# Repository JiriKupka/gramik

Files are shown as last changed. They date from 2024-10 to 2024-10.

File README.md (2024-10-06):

# Gramik

[🇬🇧 EN](README.md) | [🇨🇿 CZ](README.cs.md)

## Intro
Our little daughter enjoys music. When she was just a few months old, she received the book "[My First Mozart](https://www.axioma.cz/obchod/muj-prvni-mozart/)," which kept her entertained for countless hours. This was followed by books like "[My Little Beethoven](https://www.svojtka.cz/muj-maly-beethoven/)" or "[Rock and Roll, Baby!](https://www.axioma.cz/obchod/rokenrol-bejby-2/)." Once, we had a Chuck Berry record playing on our turntable at home. It was right around the time our daughter had just learned to walk. She stood up, leaned on the record table, and happily started shaking her hips. Around that time, the idea for the "Gramík Project" began to form in my head. The project went through several iterations—from a prototype made of ready-made modules on a breadboard, to the first PCB design with the thought of giving it some form, and finally to the current version, which I felt I could release and make available to everyone.

My main idea was to create a simple music box with a few buttons that would recognize what playlist or folder to play when a certain medium is placed on it and a button is pressed. The choice of identification medium fell on RFID chips, with an easily available and inexpensive RFID reader on the Gramík side. The first prototype was built using an ESP8266 and an MP3 module, which worked nicely, but I wanted the whole solution to be more compact, so I iterated to the version with a Raspberry Pi on a PCB.

| | | |
| --- | --- | --- |
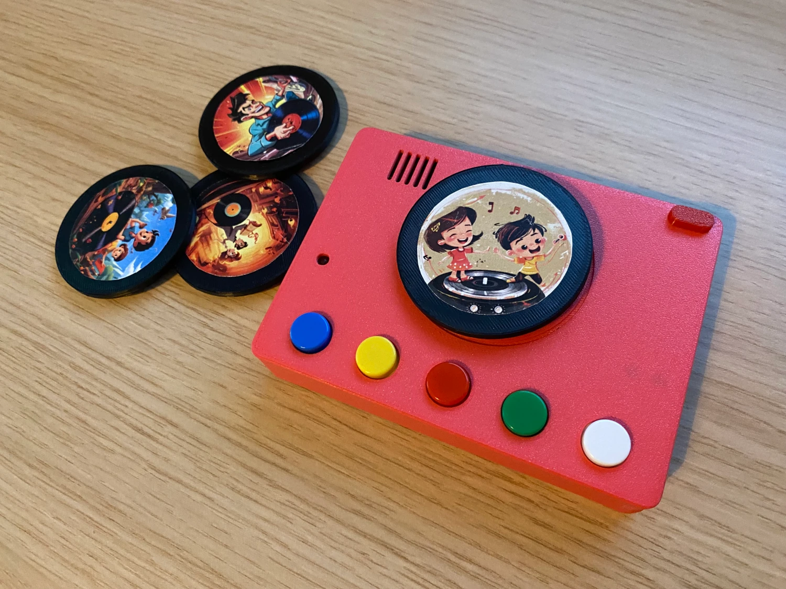
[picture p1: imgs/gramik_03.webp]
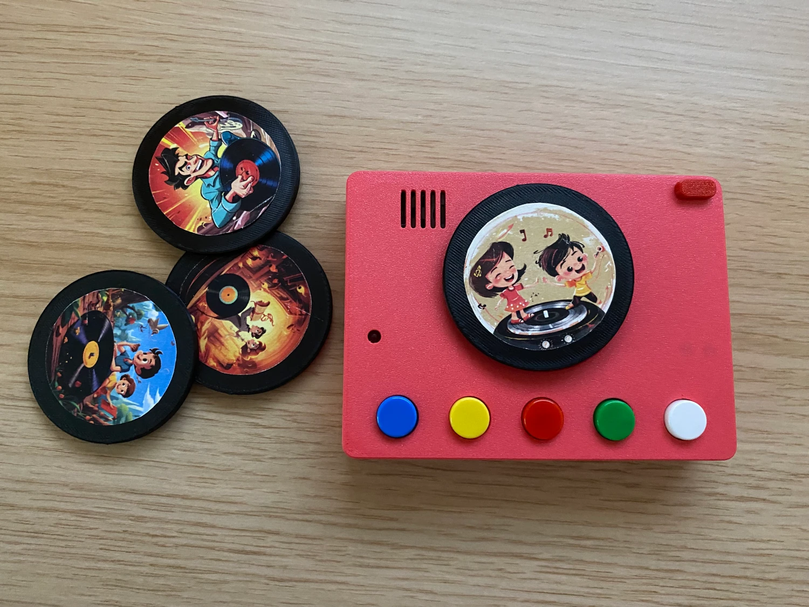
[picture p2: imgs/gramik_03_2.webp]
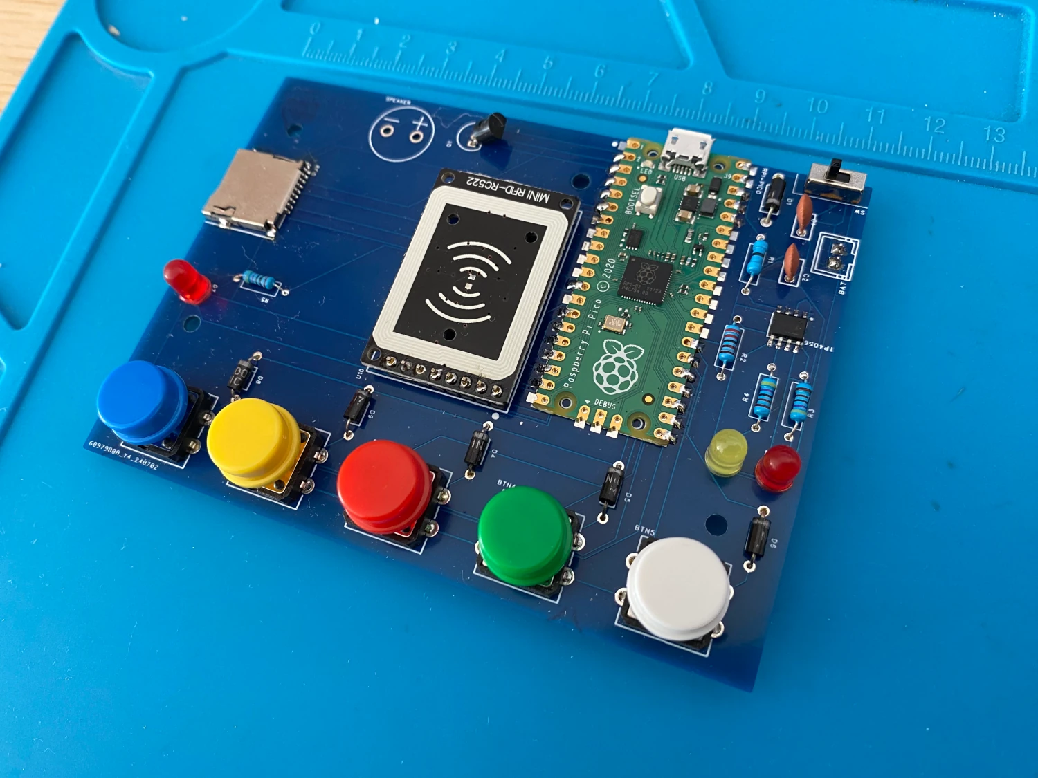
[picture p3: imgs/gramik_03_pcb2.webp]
|  |  |  |

## Implementation

### Raspberry PI Pico + CircuitPython
1. [Install CircuitPython on Raspberry Pi Pico](https://learn.adafruit.com/getting-started-with-raspberry-pi-pico-circuitpython/circuitpython)
2. [If you are using OSX, you might encounter an issue when writing new files](https://learn.adafruit.com/welcome-to-circuitpython/troubleshooting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)
3. Copy the code from the `/src/circuitpython/` directory of the repository to your Raspberry Pi Pico.

### Preparing Your Own Music and "gramophone discs"
Prepare an SD card and create any number of directories in its root, where each directory will represent one playable "gramophone disc." The directory names are not important, but I recommend keeping them in alphabetical order, as this is the order in which the directories will be registered to the RFID tag IDs.

In the original design, Gramík has 5 buttons, each representing 5 mp3 files within a directory. Once your music is ready, insert the SD card into the slot and start Gramík. Get your RFID tags/stickers/cards ready. Place each RFID tag on the reader and press any button. At this point, the tag's ID is read, and the first directory on the SD card that doesn't match the format in which this ID is encoded will be found. The directory will then be renamed to match this format. This process assigns the tag to a specific directory containing music. From now on, when this tag is placed on the reader, pressing one of the five buttons will play one of the five mp3 files from the corresponding directory.

## Variants
This project and repository should primarily serve as inspiration. Gramík as such can be freely modified. Merge requests and issues are welcome.

### Primary design
You can use the proposed circuit board according to the attached Gerber file in the repository, or alternatively, use your preferred ready-made modules.

- Raspberry PI Pico - [rpishop.cz](https://rpishop.cz/raspberry-pi-pico/5117-raspberry-pi-pico.html) | [Official store](https://www.raspberrypi.com/products/raspberry-pi-pico/)
- TP4056 charging module - [Laskakit](https://www.laskakit.cz/nabijecka-li-ion-clanku-tp4056-s-ochranou-usb-c/) | [Aliexpress](https://www.aliexpress.com/item/1005006307081697.html)
- RC522 RFID reader (ideally a mini version) - [Laskakit](https://www.laskakit.cz/rfid-ctecka-s-vestavenou-antenou-mfrc-522-rc522/) | [Aliexpress](https://www.aliexpress.com/item/1005005762707655.html)
- SD card module - [Laskakit](https://www.laskakit.cz/sd-card-modul-spi/) | [Aliexpress](https://www.aliexpress.com/item/1005005302035188.html)
- Buttons - [Laskakit](https://www.laskakit.cz/laskkit-sada-25-tlacitek-12x12x7-3mm-s-knofliky/) | [Aliexpress](https://www.aliexpress.com/item/1005007078128171.html)
- Velcro (circles) - [sevt.cz](https://www.sevt.cz/produkt/suchy-zip-samolepici-kolecka-%C3%B810-mm-63-ks-bila-25041963416) | [Aliexpress](https://www.aliexpress.com/item/1005007177045435.html)
- RFID 13,56 Mhz card or sticker - [Laskakit](https://www.laskakit.cz/rfid-13-56mhz-karta/) | [Aliexpress](https://www.aliexpress.com/item/1005003477760991.html)
- LiPol battery - [Laskakit](https://www.laskakit.cz/baterie-li-po-3-7v-1500mah-lipo/)
- 3D printer 🙂

### Alternative 1
- ESP8266 (any, for example, Wemos D1 mini) - [Laskakit](https://www.laskakit.cz/wemos-d1-mini-esp8266-wifi-modul/) | [Aliexpress](https://www.aliexpress.com/item/1005005658563136.html)
- Mini MP3 player - [Laskakit](https://www.laskakit.cz/audio-mini-mp3-prehravac/) | [Aliexpress](https://www.aliexpress.com/item/1005005656568976.html)
- Wemos D1 battery shield - [Laskakit](https://www.laskakit.cz/wemos-d1-mini-lithium-battery-shield-2) | [Aliexpress](https://www.aliexpress.com/item/1005005687704614.html)
- RC522 RFID reader (ideally a mini version) - [Laskakit](https://www.laskakit.cz/rfid-ctecka-s-vestavenou-antenou-mfrc-522-rc522/) | [Aliexpress](https://www.aliexpress.com/item/1005005762707655.html)
- Buttons - [Laskakit](https://www.laskakit.cz/laskkit-sada-25-tlacitek-12x12x7-3mm-s-knofliky/) | [Aliexpress](https://www.aliexpress.com/item/1005007078128171.html)
- Velcro (circles) - [sevt.cz](https://www.sevt.cz/produkt/suchy-zip-samolepici-kolecka-%C3%B810-mm-63-ks-bila-25041963416) | [Aliexpress](https://www.aliexpress.com/item/1005007177045435.html)
- RFID 13,56 Mhz card or sticker - [Laskakit](https://www.laskakit.cz/rfid-13-56mhz-karta/) | [Aliexpress](https://www.aliexpress.com/item/1005003477760991.html)
- LiPol battery - [Laskakit](https://www.laskakit.cz/baterie-li-po-3-7v-1500mah-lipo/)

## Assets

- `disc-images` - cover images for your discs (you can print 65mm diameter discs on a 3D printer from the included STL file).
- `mc-images` - cover images that resemble an audio cassette, for a standard access card.
- `stl` - contains a case that fits the included circuit board from the gerber directory and a 55mm disc representing a vinyl record.
- `gerber` - contains the PCB for manufacturing.
- `schema` - the primary schematic, which can be used to produce Gramík.

## TODOs and ideas
- Better power consumption - turning off the RFID module.
- Volume control.
- Add the option for audio output to a jack connector.
- Improve the case design - especially for the speaker and the power switch.

## Handy commands
```
for F in $(ls .); do ffmpeg -i "$F" -map 0:a:0 -ar 24000 -ab 64000 -ac 1 "C_$F"; done;
```

## Do you like it?

☕️ Do you like the project or has it inspired you? Buy me a coffee.

- [Buy me a Coffee](https://buymeacoffee.com/gramik)
- **BTC:** bc1qw77ty492cph4hqw4rhyege9garkkel96jr332y

## Links

- [x.com/jirikupka](https://x.com/jirikupka)

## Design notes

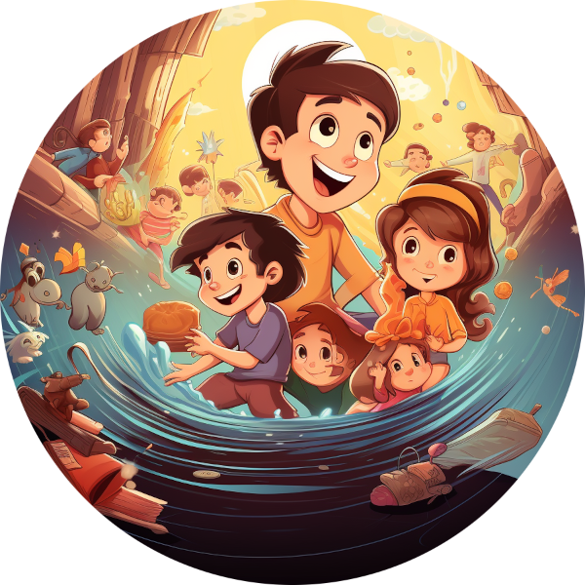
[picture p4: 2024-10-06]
assets/disc-images/kids2.png

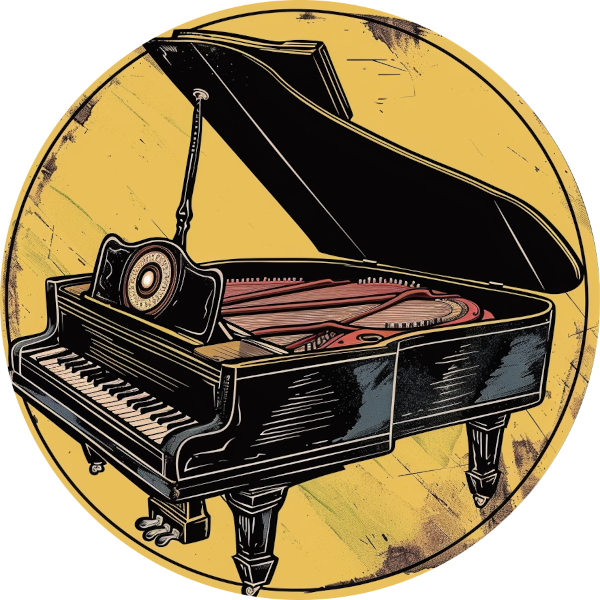
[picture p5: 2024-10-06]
assets/disc-images/classical3.png

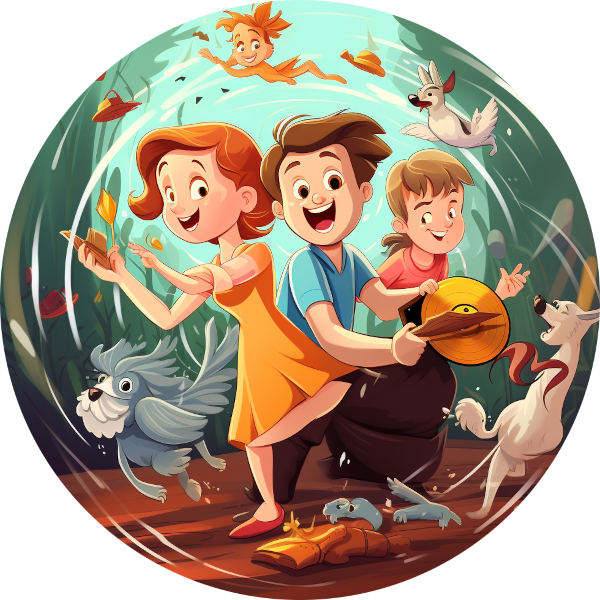
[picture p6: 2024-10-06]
assets/disc-images/kids4.png

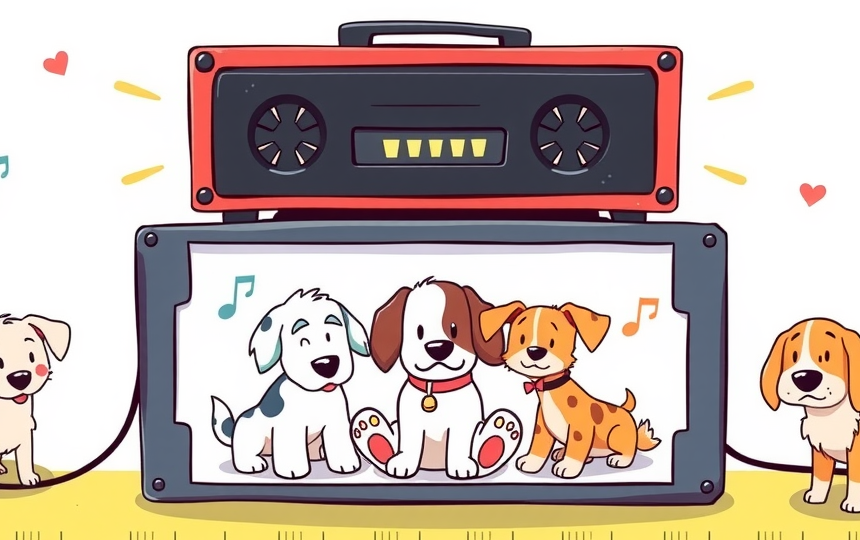
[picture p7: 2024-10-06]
assets/mc-images/dogs.png

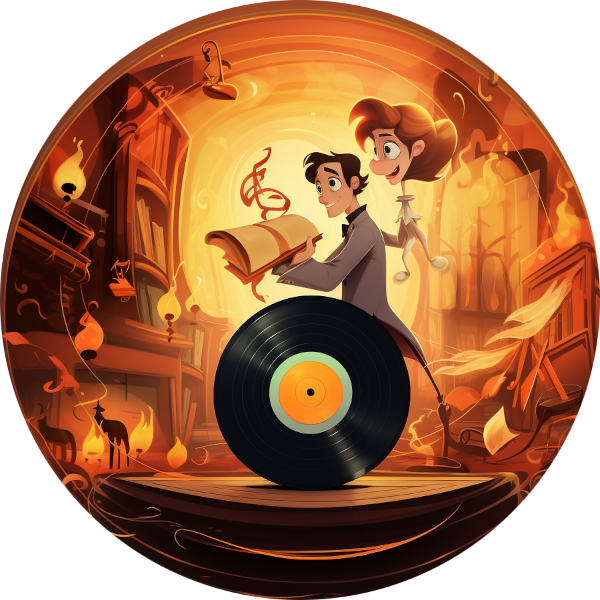
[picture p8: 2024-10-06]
assets/disc-images/classical2.png

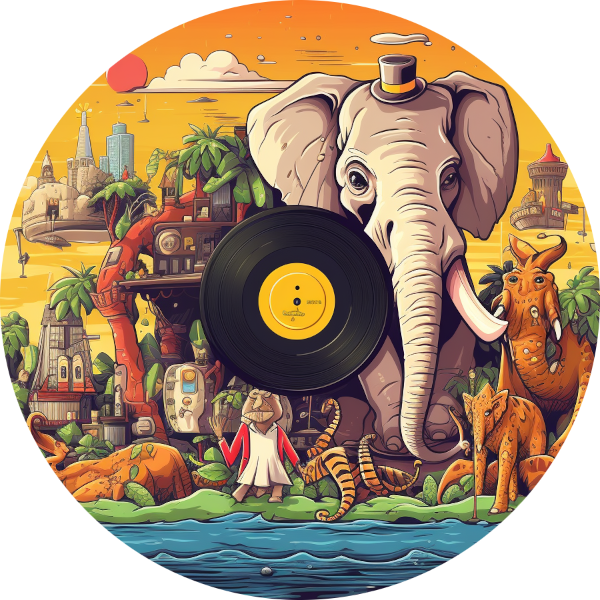
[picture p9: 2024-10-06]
assets/disc-images/animals2.png

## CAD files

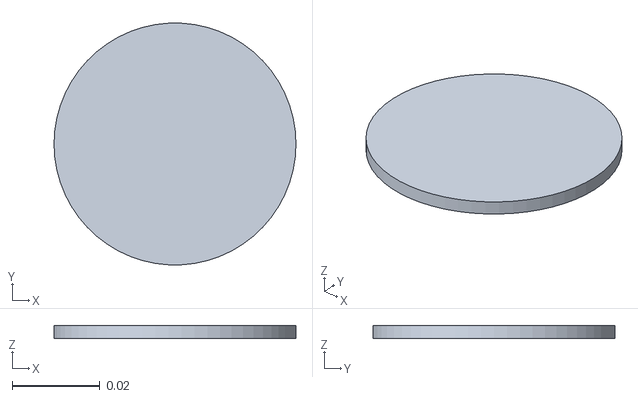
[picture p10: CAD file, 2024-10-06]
assets/stl/lp-disc-no-hole.stl
0.055 x 0.0549 x 0.003

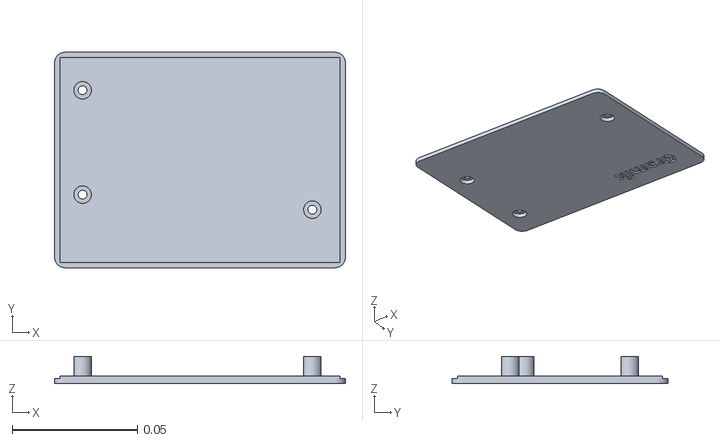
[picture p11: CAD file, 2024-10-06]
assets/stl/gramik-bottom.stl
0.116 x 0.086 x 0.0108

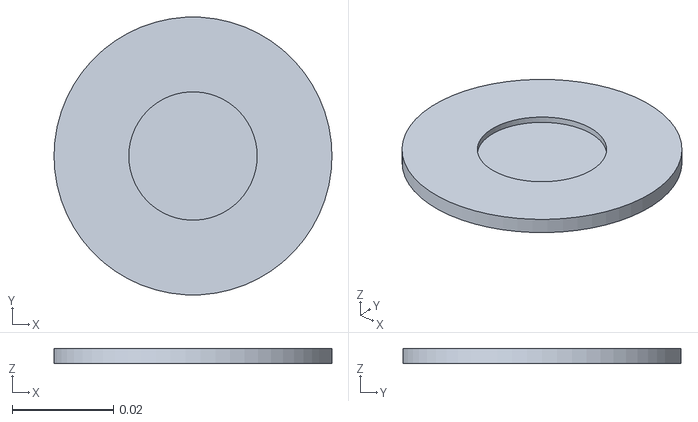
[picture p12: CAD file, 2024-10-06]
assets/stl/lp-disc-rfid-hole.stl
0.055 x 0.0549 x 0.003

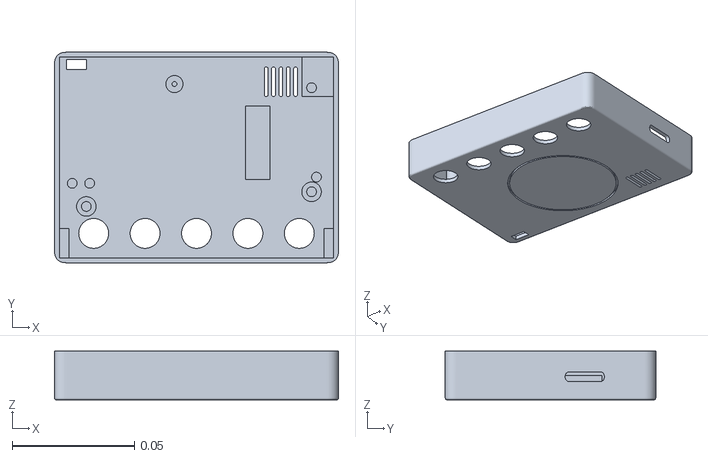
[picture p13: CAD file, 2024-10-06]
assets/stl/gramik-top.stl
0.116 x 0.086 x 0.02

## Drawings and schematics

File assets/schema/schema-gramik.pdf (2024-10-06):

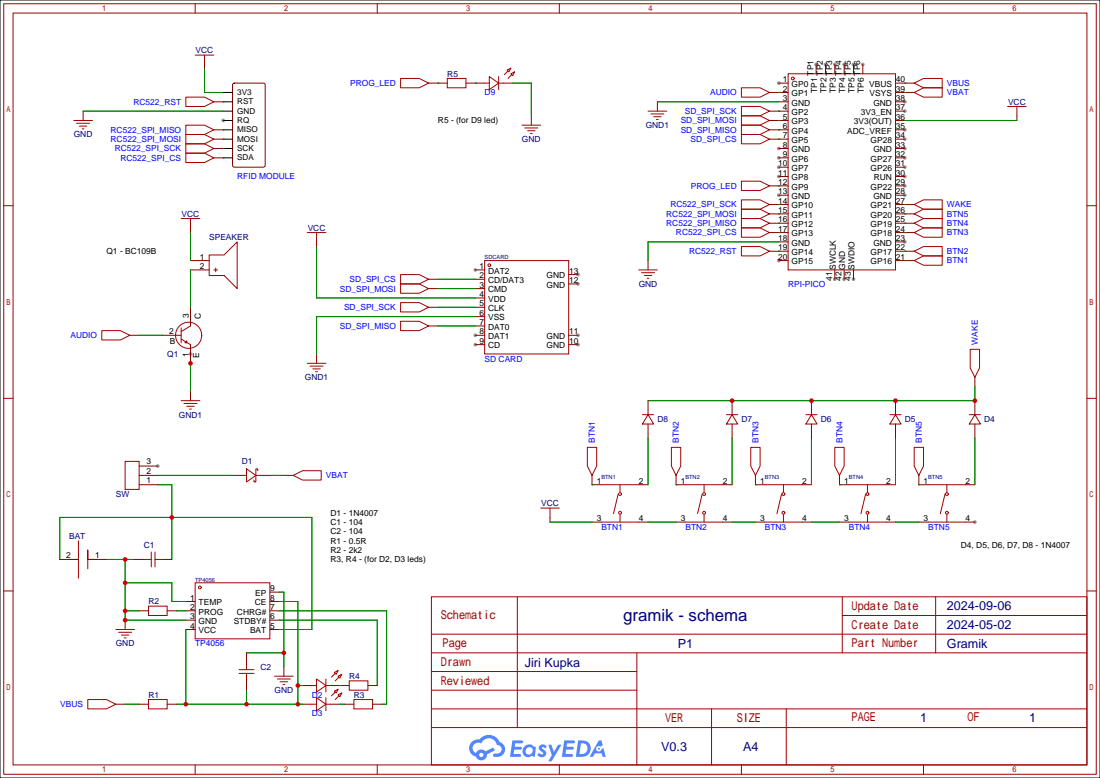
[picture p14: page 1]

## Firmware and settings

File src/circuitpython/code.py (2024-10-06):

import os

import board
import sdcardio
import storage
import busio
import time
import digitalio
import mfrc522
import audiomp3
import audiopwmio
import alarm
import pwmio
import microcontroller
import traceback


class GramikConfig:
    SD_SCK = board.GP2
    SD_MOSI = board.GP3
    SD_MISO = board.GP4
    SD_CS = board.GP5
    SD_PATH = "/sd"

    BTN1 = board.GP20
    BTN2 = board.GP19
    BTN3 = board.GP18
    BTN4 = board.GP17
    BTN5 = board.GP16

    RFID_SCK = board.GP10
    RFID_MOSI = board.GP11
    RFID_MISO = board.GP12
    RFID_CS = board.GP13
    RFID_RESET = board.GP14
    RFID_ANTENNA_GAIN = 0x04 << 4

    AUDIO_PWM = board.GP1

    PROG_LED = board.GP9
    OMNI_BUTTON = board.GP21

    SLEEP_INACTIVITY_S = 180
    DIRNAME_PREFIX = "disc_"
    ERR_LOG_PATH = SD_PATH+"/error.log"


class Gramik:

    config = None
    buttons = []
    root_dirs = []
    mp3_playlist_for_dirs = {}
    mp3_decoder = None
    audio = None

    @staticmethod
    def configure(config):
        Gramik.config = config

        Gramik.init_audio()
        Gramik.init_sd()
        Gramik.init_buttons()
        Gramik.init_rfid()
        Gramik.refresh_dirs()
        Gramik.init_prog_led()

    @staticmethod
    def init_prog_led():
        Gramik.prog_led = pwmio.PWMOut(Gramik.config.PROG_LED)

    @staticmethod
    def init_audio():
        Gramik.audio = audiopwmio.PWMAudioOut(Gramik.config.AUDIO_PWM)

    @staticmethod
    def init_sd():
        c = Gramik.config
        spi = busio.SPI(c.SD_SCK, MOSI=c.SD_MOSI, MISO=c.SD_MISO)
        sd = sdcardio.SDCard(spi, c.SD_CS)
        vfs = storage.VfsFat(sd)
        storage.mount(vfs, c.SD_PATH)

    @staticmethod
    def init_buttons():
        c = Gramik.config

        for button_gpio in [c.BTN1, c.BTN2, c.BTN3, c.BTN4, c.BTN5]:
            button = digitalio.DigitalInOut(button_gpio)
            button.direction = digitalio.Direction.INPUT
            button.pull = digitalio.Pull.DOWN
            Gramik.buttons.append(button)

    @staticmethod
    def init_rfid():
        c = Gramik.config

        Gramik.rfid = mfrc522.MFRC522(c.RFID_SCK, c.RFID_MOSI, c.RFID_MISO, c.RFID_RESET, c.RFID_CS)
        Gramik.rfid.set_antenna_gain(c.RFID_ANTENNA_GAIN)

    @staticmethod
    def refresh_dirs():
        Gramik.mp3_playlist_for_dir = {}
        Gramik.root_dirs = [dir_ for dir_ in os.listdir(Gramik.config.SD_PATH) if (os.stat(Gramik.config.SD_PATH+"/"+dir_)[0] & 0o40000 != 0) and not dir_.startswith(".")]

        for d in Gramik.root_dirs:
            dir_path = Gramik.config.SD_PATH+"/"+d
            Gramik.mp3_playlist_for_dir[d] = [dir_path+"/"+filename for filename in os.listdir(dir_path) if not filename.startswith(".")]

    @staticmethod
    def convert_uid_to_dirname(uid):
        return Gramik.config.DIRNAME_PREFIX+("_".join(map(str, uid)))

    @staticmethod
    def rename_root_dir_for_uid(uid):
        for dirname in Gramik.root_dirs:
            if not dirname.startswith(Gramik.config.DIRNAME_PREFIX):
                old_dir = "{0}/{1}".format(Gramik.config.SD_PATH, dirname)
                new_dir = "{0}/{1}".format(Gramik.config.SD_PATH, Gramik.convert_uid_to_dirname(uid))

                os.mkdir(new_dir)
                for f in os.listdir(old_dir):
                    os.rename("{0}/{1}".format(old_dir, f), "{0}/{1}".format(new_dir, f))
                os.rmdir(old_dir)

                break

        Gramik.refresh_dirs()

    @staticmethod
    def get_mp3_path(dirname, index):
        return Gramik.mp3_playlist_for_dir[dirname][index] if len(Gramik.mp3_playlist_for_dir[dirname]) > index else None

    @staticmethod
    def play_mp3_file(path):
        Gramik.audio.stop()
        f = open(path, "rb")

        if not Gramik.mp3_decoder:
            Gramik.mp3_decoder = audiomp3.MP3Decoder(f)
        else:
            Gramik.mp3_decoder.file = f

        Gramik.audio.play(Gramik.mp3_decoder)


    @staticmethod
    def turn_prog_led_on():
        Gramik.prog_led.duty_cycle = 2**10


    @staticmethod
    def run():
        Gramik.turn_prog_led_on()

        state_changed = False
        last_pressed_button_index = -1
        is_button_pressed = False
        start_time = None

        while True:

            if not Gramik.audio or not Gramik.audio.playing:
                if not start_time:
                    start_time = time.monotonic()
                if time.monotonic()-start_time > Gramik.config.SLEEP_INACTIVITY_S:
                    pin_alarm = alarm.pin.PinAlarm(pin=Gramik.config.OMNI_BUTTON, value=True, pull=True)
                    alarm.exit_and_deep_sleep_until_alarms(pin_alarm)


            pressed_buttons_list = [i for i, button in enumerate(Gramik.buttons) if button.value]
            if not pressed_buttons_list:
                is_button_pressed = False
                time.sleep(0.05)
                continue

            btn_index = pressed_buttons_list[0]
            start_time = None
            print("Button pressed", btn_index)

            if not is_button_pressed:
                is_button_pressed = True
                state_changed = True
            elif is_button_pressed:
                state_changed = False
                time.sleep(0.05)
                continue

            if last_pressed_button_index == btn_index and Gramik.audio.playing:
                Gramik.audio.stop()
                continue

            if state_changed:
                Gramik.rfid.init()

                (stat, _) = Gramik.rfid.request(Gramik.rfid.REQIDL)

                if stat == Gramik.rfid.OK:
                    (stat, raw_uid) = Gramik.rfid.anticoll()
                    select_dirname = Gramik.convert_uid_to_dirname(raw_uid)
                    if select_dirname not in Gramik.root_dirs:
                        Gramik.rename_root_dir_for_uid(raw_uid)
                    mp3_to_play = Gramik.get_mp3_path(select_dirname, btn_index)
                    if mp3_to_play:
                        Gramik.play_mp3_file(mp3_to_play)

            last_pressed_button_index = btn_index

            time.sleep(0.05)

try:
    print("Gramik is booting...")
    Gramik.configure(GramikConfig)
    Gramik.run()
except Exception as ex:
    ex_formated = traceback.format_exception(ex)
    print(ex_formated)
    with open(GramikConfig.ERR_LOG_PATH, "a") as fp:
        fp.write(ex_formated)
        fp.flush()
    microcontroller.reset()

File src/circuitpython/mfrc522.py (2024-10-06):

"""
Source: https://github.com/domdfcoding/circuitpython-mfrc522

CircuitPython Interface for RC522 boards.
"""

# 3rd party
import busio
import digitalio
from adafruit_bus_device.spi_device import SPIDevice
from microcontroller import Pin


class MFRC522:
	"""
	CircuitPython Interface for RC522 boards.

	:param sck: The SPI Clock Pin. Typically ``board.SCK``.
	:param mosi: The SPI MOSI Pin. Typically ``board.MOSI``.
	:param miso: The SPI MISO Pin. Typically ``board.MISO``.
	:param rst: The pin connected to the RST terminal on the RC522 board.
	:param cs: The SPI chip select pin, connected to the SDA terminal on the RC522 board.
	"""

	OK = 0
	NOTAGERR = 1
	ERR = 2

	REQIDL = 0x26
	REQALL = 0x52
	AUTHENT1A = 0x60
	AUTHENT1B = 0x61

	def __init__(self, sck: Pin, mosi: Pin, miso: Pin, rst: Pin, cs: Pin):

		self.cs = digitalio.DigitalInOut(cs)

		self.rst = digitalio.DigitalInOut(rst)
		self.rst.switch_to_output()

		self.rst.value = 0
		self.rst.value = 1

		self.spi = busio.SPI(sck, MOSI=mosi, MISO=miso)
		self.spi_device = SPIDevice(self.spi, self.cs)

		self.init()

	def _wreg(self, reg: int, val):

		with self.spi_device as bus_device:
			bus_device.write(b'%c' % int(0xff & ((reg << 1) & 0x7e)))
			bus_device.write(b'%c' % int(0xff & val))

	def _rreg(self, reg: int):

		with self.spi_device as bus_device:
			bus_device.write(b'%c' % int(0xff & (((reg << 1) & 0x7e) | 0x80)))
			val = bytearray(1)
			bus_device.readinto(val)

		return val[0]

	def _sflags(self, reg: int, mask: int):
		self._wreg(reg, self._rreg(reg) | mask)

	def _cflags(self, reg: int, mask: int):
		self._wreg(reg, self._rreg(reg) & (~mask))

	def _tocard(self, cmd: int, send):

		recv = []
		bits = irq_en = wait_irq = 0
		stat = self.ERR

		if cmd == 0x0E:
			irq_en = 0x12
			wait_irq = 0x10
		elif cmd == 0x0C:
			irq_en = 0x77
			wait_irq = 0x30

		self._wreg(0x02, irq_en | 0x80)
		self._cflags(0x04, 0x80)
		self._sflags(0x0A, 0x80)
		self._wreg(0x01, 0x00)

		for c in send:
			self._wreg(0x09, c)
		self._wreg(0x01, cmd)

		if cmd == 0x0C:
			self._sflags(0x0D, 0x80)

		i = 2000
		while True:
			n = self._rreg(0x04)
			i -= 1
			if ~((i != 0) and ~(n & 0x01) and ~(n & wait_irq)):
				break

		self._cflags(0x0D, 0x80)

		if i:
			if (self._rreg(0x06) & 0x1B) == 0x00:
				stat = self.OK

				if n & irq_en & 0x01:
					stat = self.NOTAGERR
				elif cmd == 0x0C:
					n = self._rreg(0x0A)
					lbits = self._rreg(0x0C) & 0x07
					if lbits != 0:
						bits = (n - 1) * 8 + lbits
					else:
						bits = n * 8

					if n == 0:
						n = 1
					elif n > 16:
						n = 16

					for _ in range(n):
						recv.append(self._rreg(0x09))
			else:
				stat = self.ERR

		return stat, recv, bits

	def _crc(self, data):

		self._cflags(0x05, 0x04)
		self._sflags(0x0A, 0x80)

		for c in data:
			self._wreg(0x09, c)

		self._wreg(0x01, 0x03)

		i = 0xFF
		while True:
			n = self._rreg(0x05)
			i -= 1
			if not ((i != 0) and not (n & 0x04)):
				break

		return [self._rreg(0x22), self._rreg(0x21)]

	def init(self):

		self.reset()
		self._wreg(0x2A, 0x8D)
		self._wreg(0x2B, 0x3E)
		self._wreg(0x2D, 30)
		self._wreg(0x2C, 0)
		self._wreg(0x15, 0x40)
		self._wreg(0x11, 0x3D)
		self.antenna_on()

	def reset(self):
		self._wreg(0x01, 0x0F)

	def antenna_on(self, on=True):

		if on and ~(self._rreg(0x14) & 0x03):
			self._sflags(0x14, 0x03)
		else:
			self._cflags(0x14, 0x03)

	def request(self, mode):

		self._wreg(0x0D, 0x07)
		(stat, recv, bits) = self._tocard(0x0C, [mode])

		if (stat != self.OK) | (bits != 0x10):
			stat = self.ERR

		return stat, bits

	def anticoll(self):

		ser_chk = 0
		ser = [0x93, 0x20]

		self._wreg(0x0D, 0x00)
		(stat, recv, bits) = self._tocard(0x0C, ser)

		if stat == self.OK:
			if len(recv) == 5:
				for i in range(4):
					ser_chk = ser_chk ^ recv[i]
				if ser_chk != recv[4]:
					stat = self.ERR
			else:
				stat = self.ERR

		return stat, recv

	def select_tag(self, ser):

		buf = [0x93, 0x70] + ser[:5]
		buf += self._crc(buf)
		(stat, recv, bits) = self._tocard(0x0C, buf)
		return self.OK if (stat == self.OK) and (bits == 0x18) else self.ERR

	def auth(self, mode, addr, sect, ser):
		return self._tocard(0x0E, [mode, addr] + sect + ser[:4])[0]

	def stop_crypto1(self):
		self._cflags(0x08, 0x08)

	def read(self, addr):

		data = [0x30, addr]
		data += self._crc(data)
		(stat, recv, _) = self._tocard(0x0C, data)
		return recv if stat == self.OK else None

	def write(self, addr, data):

		buf = [0xA0, addr]
		buf += self._crc(buf)
		(stat, recv, bits) = self._tocard(0x0C, buf)

		if not (stat == self.OK) or not (bits == 4) or not ((recv[0] & 0x0F) == 0x0A):
			stat = self.ERR
		else:
			buf = []
			for i in range(16):
				buf.append(data[i])
			buf += self._crc(buf)
			(stat, recv, bits) = self._tocard(0x0C, buf)
			if not (stat == self.OK) or not (bits == 4) or not ((recv[0] & 0x0F) == 0x0A):
				stat = self.ERR

		return stat

	def set_antenna_gain(self, gain: int):
		"""
		Set the MFRC522 Receiver Gain

		:param gain:

		Possible values are:

		* ``0x00 << 4`` -- 000b - 18 dB, minimum
		* ``0x01 << 4`` -- 001b - 23 dB
		* ``0x02 << 4`` -- 010b - 18 dB, it seems 010b is a duplicate for 000b
		* ``0x03 << 4`` -- 011b - 23 dB, it seems 011b is a duplicate for 001b
		* ``0x04 << 4`` -- 100b - 33 dB, average, and typical default
		* ``0x05 << 4`` -- 101b - 38 dB
		* ``0x06 << 4`` -- 110b - 43 dB
		* ``0x07 << 4`` -- 111b - 48 dB, maximum
		* ``0x00 << 4`` -- 000b - 18 dB, minimum, convenience for RxGain_18dB
		* ``0x04 << 4`` -- 100b - 33 dB, average, convenience for RxGain_33dB
		* ``0x07 << 4`` -- 111b - 48 dB, maximum, convenience for RxGain_48dB

		:return:
		"""

		# Above table from https://github.com/miguelbalboa/rfid/blob/master/src/MFRC522.h
		# See also 9.3.3.6 / table 98 of the datasheet (http://www.nxp.com/documents/data_sheet/MFRC522.pdf)

		self._cflags(0x26, 0x07 << 4)
		self._sflags(0x26, gain & (0x07 << 4))
